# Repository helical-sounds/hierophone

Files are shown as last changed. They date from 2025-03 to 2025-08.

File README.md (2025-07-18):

# Hierophone

The Hierophone is an instrument designed around resonating a sheet of metal by placing it in an audio feedback loop. By changing the filtering of the audio, the phase and level of feedback, and manipulating the sheet directly, different overtones and sounds can be generated.

The name derives from ancient Greek, being the combination of ἱερά (hiera, 'holy') and φωνή (phōnē, 'voice'), together meaning "Holy Voice".

## Contact

Drop me an email at guy@rumblesan.com

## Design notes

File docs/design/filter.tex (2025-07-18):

\documentclass{article}

\usepackage{amsmath}
\usepackage{graphicx}
\usepackage{enumitem}

\title{Hierophone Filter}
\author{Guy John \\ \texttt{guy@rumblesan.com}}

\begin{document}

\maketitle

\section{Introduction}
Analysis of the Hierophone filter, a basic three-pole low-pass filter built from three cascaded OTA based integrator cells.

\newpage

\subsection{Notations}

\begin{description}
\item $R_i$ is the value of the resistor through which the input signal is fed to the OTA
\item $R_s$ is the value of the resistor at the voltage divider input of the OTA
\item $R_f$ is the value of the resistor through which the integrator output is fed back to the OTA input
\item $C$ is the value of the integrators' capacitor
\item $v_{cv}$ is the cutoff frequency control voltage
\item $v_i(s)$ is the input voltage
\item $v_{out}(s)$ is the output voltage
\end{description}

\subsection{OTA Low-Pass Filter}

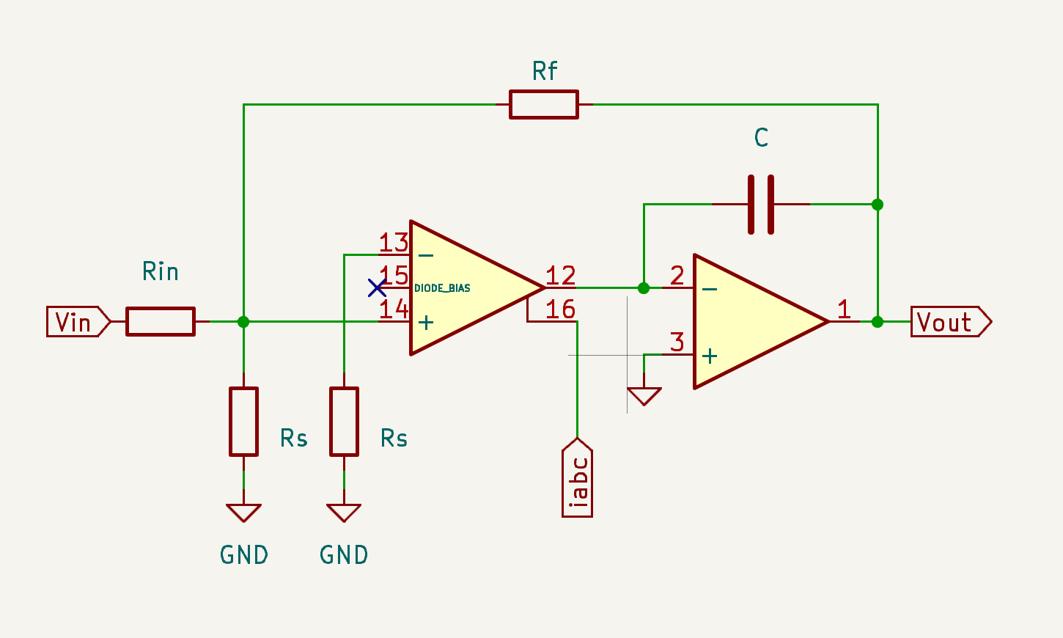
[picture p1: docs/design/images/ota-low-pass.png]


The transfer function of an OTA is:

\begin{equation*}
\begin{split}
  i_o & = g_m(v_+ - v_-) \\
  i_o & = 19.2i_{cv}(v_+ - v_-) \\
\end{split}
\end{equation*}

If $R_f == R_i == R$ then Kirchoff in $v_+$ gives:

\begin{equation*}
\begin{split}
  \frac{1}{R}(v_i(s) - v_+(s)) + \frac{1}{R}(v_{out}(s) - v_+(s)) & = \frac{1}{R_s}v_+(s) \\
  v_+(s) & = \frac{R_s}{R + 2R_s}(v_i(s) + v_{out}(s)) \\
\end{split}
\end{equation*}

Given that $v_-$ is grounded, the current $i_c(s)$ at the output of the OTA is:

\begin{equation*}
\begin{split}
  i_c(s) & = g_m(v_+(s) - v_-(s)) \\
   & = 19.2i_{cv}\frac{R_s}{R + 2R_s}(v_i(s) + v_{out}(s)) \\
\end{split}
\end{equation*}

The voltage out of the OpAmp:

\begin{equation*}
\begin{split}
  v_{out}(s) & = \frac{-i_c(s)}{Cs} \\
  v_{out}(s) & = -19.2i_{cv}\frac{R_s}{Cs(R + 2R_s)}(v_i(s) + v_{out}(s)) \\
\end{split}
\end{equation*}

So the transfer function is:

\begin{equation}
  \alpha(s) = \frac{-1}{1 + \frac{R + 2 R_s}{R_s} Cs \frac{1}{19.2 i_{cv}}}
\end{equation}

The pole is at the frequency f so that:

\begin{equation*}
\begin{split}
  0 & = 1 + \frac{R + 2R_s}{R_s} C2\pi f \frac{1}{19.2 i_{cv}} \\
  f & = - \frac{19.2 i_{cv}}{2\pi\frac{R + 2 R_s}{R_s}C}\\
\end{split}
\end{equation*}

\subsection{Feedback Control}

The gain of the feedback circuit is:

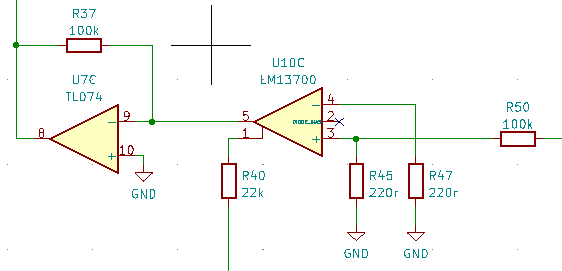
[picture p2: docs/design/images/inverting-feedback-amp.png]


\begin{equation*}
\begin{split}
  v_+ & = v_i\frac{R_s}{R + R_s} \\
  i_o & = 19.2i_{q}(v_+ - v_-) \\
  i_o & = 19.2i_{q}(v_+ - 0) \\
  i_o & = 19.2i_{q}v_i\frac{R_s}{R + R_s} \\
  i_o & = R_f(v_- - v_o) \\
  i_o & = -R_fv_o \\
  -R_fv_o & = 19.2i_{q}v_i\frac{R_s}{R + R_s} \\
  -R_fv_o & = 19.2i_{q}v_i\frac{R_s}{R + R_s} \\
  v_o & = -19.2i_{q}v_i\frac{R_fR_s}{R_i + R_s} \\
  \beta & = -19.2i_{q}\frac{R_fR_s}{R_i + R_s} \\
\end{split}
\end{equation*}

\subsection{Filter}

\begin{equation*}
\begin{split}
  \frac{v_i - v_-}{R_i} + \frac{v_{hp} - v_-}{R_g} + \frac{v_{lp} - v_-}{R_g}  + \frac{v_{bp}\beta - v_-}{R_q} & = i_- = 0 \\
  \frac{v_i}{R_i} + \frac{v_{hp}}{R_g} + \frac{v_{lp}}{R_g}  + \frac{v_{bp}\beta}{R_q} & = 0 \\
\end{split}
\end{equation*}

It is important to note that $v_{bp}(s) = v_{hp}(s)\alpha(s)$, and $v_{lp}(s) = v_{hp}(s)\alpha(s^2)$.

\subsubsection{High-pass}

\begin{equation*}
\begin{split}
  \frac{v_{hp}(s)}{R_g} & = - \frac{v_i(s)}{R_i} - \frac{v_{lp}(s)}{R_g} - \frac{v_{bp}(s)\beta}{R_q} \\
  \frac{v_{hp}(s)}{R_g} & = - \frac{v_i(s)}{R_i} - \frac{v_{hp}(s)\alpha(s^2)}{R_g} - \frac{v_{hp}(s)\alpha(s)\beta}{R_q} \\
  \frac{v_i(s)}{R_i} & = - \frac{v_{hp}(s)}{R_g} - \frac{v_{hp}(s)\alpha(s^2)}{R_g} - \frac{v_{hp}(s)\alpha(s)\beta}{R_q} \\
  H_{hp}(s) & = \frac{v_{hp}(s)}{v_i(s)} \\
  \frac{v_i(s)}{R_i} & = - v_{hp}(s)(\frac{1}{R_g} + \frac{\alpha(s^2)}{R_g} + \frac{\alpha(s)\beta}{R_q}) \\
  \frac{1}{R_i} & = - H_{hp}(s)(\frac{1}{R_g} + \frac{\alpha(s^2)}{R_g} + \frac{\alpha(s)\beta}{R_q}) \\
  \frac{-1}{R_i} & = H_{hp}(s)(\frac{1}{R_g} + \frac{\alpha(s^2)}{R_g} + \frac{\alpha(s)\beta}{R_q}) \\
  H_{hp}(s) & = \frac{-1/R_i}{\frac{1}{R_g} + \frac{\alpha(s^2)}{R_g} + \frac{\alpha(s)\beta}{R_q}} \\
  & = \frac{-R_g/R_i}{1 + \frac{R_g\alpha(s)\beta}{R_q} + \alpha(s^2) } \\
\end{split}
\end{equation*}

\subsubsection{Low-Pass}

\begin{equation*}
\begin{split}
  H_{lp}(s) & = \frac{v_{lp}(s)}{v_i(s)} \\
            & = \frac{v_{hp}(s)}{v_i(s)}\alpha^2(s) \\
            & = \frac{-R_g/R_i}{\frac{1}{\alpha^2(s)} + \frac{R_g\beta}{R_q\alpha(s)} + 1 } \\
            & = \frac{-R_g/R_i}{\frac{1}{\alpha^2(s)} + \beta\frac{R_g}{R_q}\frac{1}{\alpha(s)} + 1 } \\
            & = \frac{-R_g/R_i}{\frac{1}{(-19.2i_{cv}\frac{R_s}{Cs(R + 2R_s)})^2} + (-19.2i_{q}\frac{R_fR_s}{R_i + R_s})\frac{R_g}{R_q}\frac{1}{-19.2i_{cv}\frac{R_s}{Cs(R + 2R_s)}} + 1 } \\
            & = \frac{-R_g/R_i}{\frac{1}{(19.2i_{cv}\frac{R_s}{Cs(R + 2R_s)})^2} + 19.2i_{q}\frac{R_fR_s}{R_i + R_s}\frac{R_g}{R_q}\frac{1}{19.2i_{cv}\frac{R_s}{Cs(R + 2R_s)}} + 1 } \\
            & = \frac{-R_g/R_i}{\frac{1}{\frac{1}{s^2}(19.2i_{cv}\frac{R_s}{C(R + 2R_s)})^2} + 19.2i_{q}\frac{R_fR_s}{R_i + R_s}\frac{R_g}{R_q}\frac{1}{19.2i_{cv}\frac{1}{s}\frac{R_s}{C(R + 2R_s)}} + 1 } \\
            & = \frac{-R_g/R_i}{\frac{s^2}{(19.2i_{cv}\frac{R_s}{C(R + 2R_s)})^2} + 19.2i_{q}\frac{R_fR_s}{R_i + R_s}\frac{R_g}{R_q}\frac{s}{19.2i_{cv}\frac{R_s}{C(R + 2R_s)}} + 1 } \\
\end{split}
\end{equation*}

One simplification worth making is to say that $R_q = R_g$.

By comparing with the standard form of a second order filter transfer function we can work out the following.

\begin{description}
  \item Pass-band gain, $-\frac{R_g}{R_i}$
  \item Cutoff frequency, $19.2i_{cv}\frac{R_s}{C2\pi(R + 2R_s)}$
  \item Quality factor, $\frac{1}{19.2i_{q}\frac{R_fR_s}{R_i + R_s}}$
\end{description}

\subsection{Calculating cutoff frequencies}

Given the calculation for frequency, and picking some standard values we can calculate cutoff for different $i_{cv}$ values.

\begin{description}
  \item $R$ is 100k
  \item $R_s$ is 220r
  \item $C$ is 220pF
\end{description}

\begin{equation}
  f = 19.2i_{cv}\frac{220}{220 * 10^{-12} * 2\pi(100000 + 2(220))}
\end{equation}

\begin{description}
  \item for $i_{cv}$ of 0.5ma $f = 15212Hz$
  \item for $i_{cv}$ of 0.3ma $f = 9127Hz$
  \item for $i_{cv}$ of 0.1ma $f = 3042Hz$
  \item for $i_{cv}$ of 0.05ma $f = 1521Hz$
  \item for $i_{cv}$ of 0.01ma $f = 304Hz$
\end{description}

\subsection{Calculating resonance}

A quality factor of $1/2$ gives no resonance, whilst the resonance (and likelihood of self oscillating) increases as Q goes to infinity.

\begin{description}
  \item $R_f$ is 100k
  \item $R_i$ is 100k
  \item $R_s$ is 220r
  \item $C$ is 220pF
\end{description}

\begin{equation}
  q = \frac{1}{19.2i_{q}\frac{100000 * 220}{100000 + 220}}
\end{equation}

\begin{description}
  \item for $i_{q}$ of 0.5ma $q = 0.47$
  \item for $i_{q}$ of 0.3ma $q = 0.79$
  \item for $i_{q}$ of 0.1ma $q = 2.37$
  \item for $i_{q}$ of 0.05ma $q = 4.75$
  \item for $i_{q}$ of 0.01ma $q = 23.7$
\end{description}

\end{document}

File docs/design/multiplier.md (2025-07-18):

# multiplier

control current circuitry

iabc = Vc/100k * (1k5 + 33k)/1k5

5 = 1.15ma
1.2 = 0.05 * (r + 33k)/r
1.2r = 0.05r + 1.65
1.15r = 1.65

0v   = 0ma
2.5v = 0.575ma
5v   = 1.15ma

OTA current out = 19.2 * iabc * vIn * 220/(100k+220)
vOut = vIn - (OTA current out * 47k)
vOut = vIn - (vIn * iabc * 0.042 * 47k)
vOut/vIn = Gain = 1 - iabc * 0.042 * 47k

Think control circuitry pot directions need flipping

0v input should be gain of 1

2.5v input should be gain of 0
2.5v == 0.575ma
0 = 1 - 0.575 * 0.042 * Rout
0.02415 Rout = 1
Rout should be 41k

5v input should be gain of -1
5v == 1.7ma
-1 = 1 - 1.7 * 0.042 * 28k
0.0714 Rout = 2
Rout should be 28k

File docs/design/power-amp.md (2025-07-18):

# Power Amp Design

The power amp for the Heirophone is just an LM386 powered from the +12v supply. To make sure the chip doesn't overheat and blow up, it's important to work out the voltage input range for a given power output and make sure it operates within those limits.

The [LM386 data sheet][lm386-datasheet] gives all the required information.

When running from a 12v supply, and running into a 4ohm load like the surface transducer, the peak-to-peak output voltage will max out at about 3.8 volts. This means the maximum power output we'll be able to get would be :-

```
vRMS = (vPtoP / 2) * 0.707
vRMS = 1.3433v

power = (vRMS ^ 2) / 4ohms = 0.45W
```

Based on the distortion figures, as well as the devices power dissipation based on power output, the aim is to keep the actual power output to about 0.13W maximum. This means the peak to peak voltage across the speaker should be roughly :-

```
sqrt(0.13W * 4ohms) = 0.721 vRMS

(0.721 vRMS / 0.707) * 2 = 2.04 vPtoP
```

Given the default gain of the LM386 is 20, this means the input voltage should be around 0.1 vPtoP

In theory the output from the opamp just prior to the power amp could be 12 vPtoP meaning ideally there is a gain reduction of 120 to keep within the right limits.

[lm386-datasheet]: https://www.ti.com/lit/ds/symlink/lm386.pdf

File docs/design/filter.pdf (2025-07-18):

# Hierophone Filter

Guy John
guy@rumblesan.com

July 14, 2025

## 1 Introduction

Analysis of the Hierophone filter, a basic three-pole low-pass filter built from three cascaded OTA based integrator cells.

1

### 1.1 Notations

Ri

is the value of the resistor through which the input signal is fed to the OTA

Rs is the value of the resistor at the voltage divider input of the OTA

Rf is the value of the resistor through which the integrator output is fed back to the OTA input

C is the value of the integrators’ capacitor

vcv is the cutoff frequency control voltage

vi(s) is the input voltage

vout(s) is the output voltage

### 1.2 OTA Low-Pass Filter

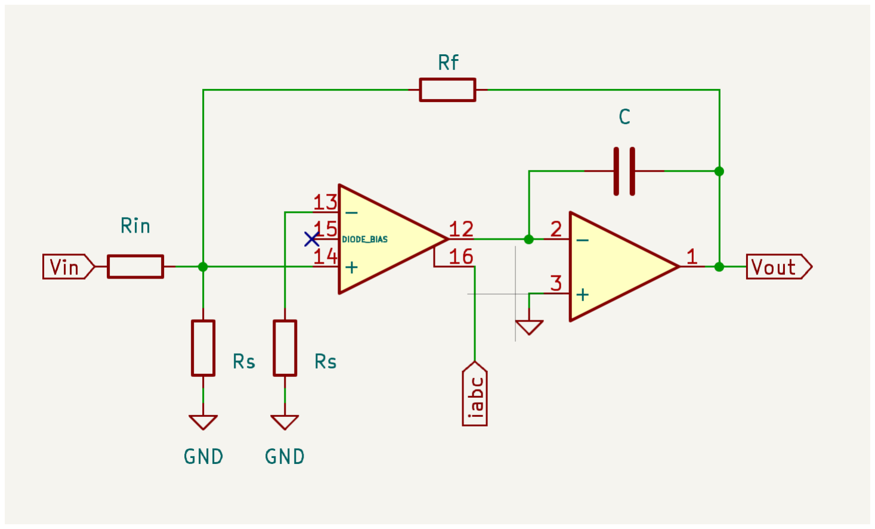
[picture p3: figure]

The transfer function of an OTA is:

io = gm(v+ − v−)
io = 19.2icv(v+ − v−)

If Rf == Ri == R then Kirchoff in v+ gives:

1
R

(vi(s) − v+(s)) + 1
R

(vout(s) − v+(s)) = 1
Rs

v+(s)

v+(s) = Rs R + 2Rs
(vi(s) + vout(s))

2

Given that v− is grounded, the current ic(s) at the output of the OTA is:

ic(s) = gm(v+(s) − v−(s))

= 19.2icv

Rs
R + 2Rs

(vi(s) + vout(s))

The voltage out of the OpAmp:

vout(s) = −ic(s)
Cs

vout(s) = −19.2icv

Rs
Cs(R + 2Rs)

(vi(s) + vout(s))

So the transfer function is:

α(s) = | −1

1 + R+2Rs
Rs

Cs 1
19.2icv

(1)

The pole is at the frequency f so that:

0 = 1 +

R + 2Rs
Rs

C2πf 1 19.2icv

f = −

19.2icv
2π

R+2Rs
Rs

C

### 1.3 Feedback Control

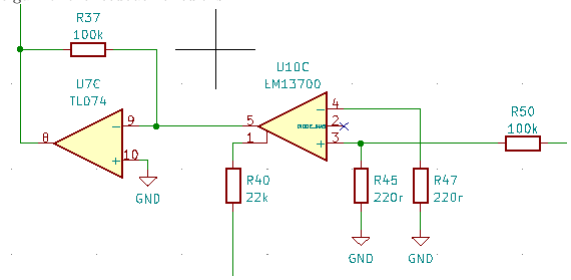
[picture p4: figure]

The gain of the feedback circuit is:

3

v+ = vi

Rs
R + Rs
io = 19.2iq(v+ − v−)
io = 19.2iq(v+ − 0)

io = 19.2iqvi

Rs
R + Rs
io = Rf (v− − vo)
io = −Rf vo

−Rf vo = 19.2iqvi

Rs
R + Rs

−Rf vo = 19.2iqvi

Rs
R + Rs

vo = −19.2iqvi

RfRs
Ri + Rs

β = −19.2iq

RfRs
Ri + Rs

### 1.4 Filter

vi − v−
Ri

+

vhp − v−
Rg

+

vlp − v−
Rg

+

vbpβ − v−
Rq

= i− = 0

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
vbpβ
Rq

= 0

It is important to note that vbp(s) = vhp(s)α(s), and vlp(s) = vhp(s)α(s

2
).

4

### 1.4.1 High-pass

vhp(s)
Rg

= −

vi(s)
Ri

−

vlp(s)
Rg

−

vbp(s)β
Rq
vhp(s)
Rg

= −

vi(s)
Ri

−

vhp(s)α(s

2
)
Rg

−

vhp(s)α(s)β
Rq
vi(s)
Ri

= −

vhp(s)
Rg

−

vhp(s)α(s

2
)
Rg

−

vhp(s)α(s)β
Rq
Hhp(s) = vhp(s)
vi(s)
vi(s)
Ri

= −vhp(s)( 1
Rg

+

α(s

2
)
Rg

+

α(s)β
Rq

)

1
Ri

= −Hhp(s)( 1
Rg

+

α(s

2
)
Rg

+

α(s)β
Rq

)

−1
Ri

= Hhp(s)( 1
Rg

+

α(s

2
)
Rg

+

α(s)β
Rq

)

Hhp(s) = | −1/Ri

1
Rg

+

| α(s 2) Rg +
α(s)β
Rq
= | −Rg/Ri 1 + Rgα(s)β Rq + α(s

2)

5

### 1.4.2 Low-Pass

Hlp(s) = vlp(s)
vi(s)

=

vhp(s)
vi(s)

α

2
(s)

=

−Rg/Ri

1
α²(s) +

Rgβ
Rqα(s) + 1

=

−Rg/Ri

1
α²(s) + β

Rg
Rq

1
α(s) + 1

=

−Rg/Ri

1
(−19.2icv

Rs
Cs(R+2Rs)

)

2 + (−19.2iq

Rf Rs
Ri+Rs

)

Rg
Rq

1
−19.2icv

Rs
Cs(R+2Rs)

+ 1

=

−Rg/Ri

1
(19.2icv

Rs
Cs(R+2Rs)

)

2 + 19.2iq

Rf Rs
Ri+Rs

Rg
Rq

1
19.2icv

Rs
Cs(R+2Rs)

+ 1

=

−Rg/Ri

1
1
s2

(19.2icv

Rs
C(R+2Rs)

)

2 + 19.2iq

Rf Rs
Ri+Rs

Rg
Rq

1
19.2icv

1
s

Rs
C(R+2Rs)

+ 1

=

−Rg/Ri

s

2
(19.2icv

Rs
C(R+2Rs)

)

2 + 19.2iq

Rf Rs
Ri+Rs

Rg
Rq

s
19.2icv

Rs
C(R+2Rs)

+ 1

One simplification worth making is to say that Rq = Rg.
By comparing with the standard form of a second order filter transfer function we can work out the following.

Pass-band gain, −

Rg
Ri

Cutoff frequency, 19.2icv

Rs
C2π(R+2Rs)
Quality factor, 1
19.2iq
| Rf Rs Ri+Rs

### 1.5 Calculating cutoff frequencies

Given the calculation for frequency, and picking some standard values we can calculate cutoff for different icv values.

R is 100k

Rs is 220r

C is 220pF

f = 19.2icv

220
220 ∗ 10⁻¹² ∗ 2π(100000 + 2(220)) | (2)

6

for icv of 0.5ma f = 15212Hz

for icv of 0.3ma f = 9127Hz

for icv of 0.1ma f = 3042Hz

for icv of 0.05ma f = 1521Hz

for icv of 0.01ma f = 304Hz

### 1.6 Calculating resonance

A quality factor of 1/2 gives no resonance, whilst the resonance (and likelihood of self oscillating) increases as Q goes to infinity.

Rf is 100k

Ri

is 100k

Rs is 220r

C is 220pF

q =

1
19.2iq

100000∗220
100000+220

(3)

for iq of 0.5ma q = 0.47

for iq of 0.3ma q = 0.79

for iq of 0.1ma q = 2.37

for iq of 0.05ma q = 4.75

for iq of 0.01ma q = 23.7

7

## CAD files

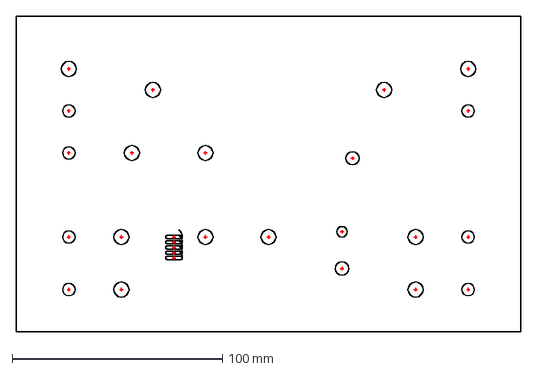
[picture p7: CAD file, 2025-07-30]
panels/panel-holes.dxf
240.0 x 150.0 mm

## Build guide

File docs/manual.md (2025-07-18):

# Hierophone

The Hierophone is an instrument designed around resonating a sheet of metal by placing it in an audio feedback loop. By changing the filtering of the audio, the phase and level of feedback, and manipulating the sheet directly, different overtones and sounds can be generated.

The name derives from ancient Greek, being the combination of ἱερά (hiera, 'holy') and φωνή (phōnē, 'voice'), together meaning "Holy Voice".

## Background

At the beginning of 2025 I visited the home/workshop of [Sam Underwood](https://www.mrunderwood.co.uk/) where he showed a wild range of interesting instruments and oddities he'd designed and made. One of these involved using part of his "Acoustic Modular" to excite a small steel plate with a surface transducer, pick the sound up using a piezo contact microphone, and then feed the output back to the input to make the plate resonate, using a low pass filter and some magnets to influence the sound.

It was great!
So I decided to build my own version.

## Warnings

It is very easy to make a lot of loud, dissonant, screeching noise with the Hierophone. Whilst this is obviously part of the appeal of the instrument, it's worth exercising a bit of caution when first getting used to playing it.

As well as potentially painful sounds, it's also worth pointing out that a thin sheet of steel can have potentially sharp edges and cause damage to tabletops, floors, furniture and hands if you're not careful with it.

## Power

The Hierophone is designed to be run from a 9 volt, centre negative power supply. It should also work fine from 12 volts, but prolonged usage will make the power amp a bit warmer.

## Operation

The signal flow of the Hierophone is relatively simple, with the complexity really coming from the interaction of everything. Whilst it has audio inputs and outputs, it can be played alone with the sounds generated by the plate itself.

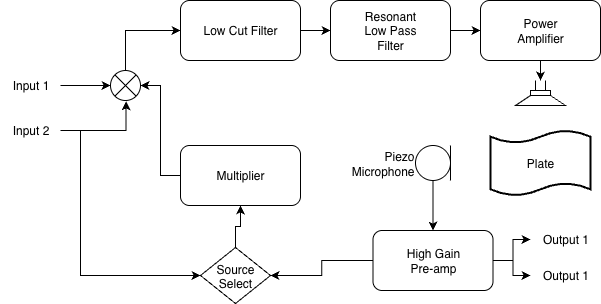
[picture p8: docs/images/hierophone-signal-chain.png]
Hierophone Signal Chain


#### Inputs

There are two inputs, both with individual volume controls, which can accept both line-level and modular synth level signals. These are mixed together along with the audio being fed back from the output.

#### Low-cut Filter

It can sometimes be useful to cut some of the low frequencies being fed into the plate to try and make it resonate with higher harmonics. This is a basic 6db/octave, non-resonant, high-pass filter with a variable frequency cut-off from about 350Hz down to 0Hz.

#### Resonant Low-pass Filter

Audio feedback can result in a lot of high frequencies, especially with the steel plate resonance. This filter helps to tame that, as well as allowing some influence over how the plate resonates and what overtones will sound out.

It is a three-pole, 18db/octave, low-pass filter with control over the cut-off frequency and resonance. The cut-off is also CV controllable by another source, with an attenuverter on the input.

#### Power Amplifier

The power amplifier is responsible for driving the surface transducer that excites the plate. The "Plate Drive" controls how much the surface transducer will be driven by the amplifier.

#### Surface Transducer

The transducers

#### High-Gain Piezo Amplifier

An amplifier designed specifically to handle the high output impedance of a piezo contact microphone. The "Pickup Gain" controls how much the input from the piezo is amplified.

#### Feedback Multiplier

When interacting with feedback in complex systems, the phase of the signal can be as important as the magnitude in changing how the system behaves. The multiplier allows smoothly changing both of these things with a single control. Fully clockwise will feed the full signal back to the input, while fully anti-clockwise will still feed the full signal, but inverted to be 180 degrees out of phase.

Positioning the control at 12 o'clock will result in no signal being fed back to the input.

This parameter is also fully CV controllable with an attenuverter on the input. It's worth noting that if you have an external oscillator then the multiplier can function as a ring-modulator, giving access to all sorts of metallic sound generation.

Finally, there is a switch to select whether the audio fed back to the input comes from the piezo amplifier, or instead from the second input before its volume control. This makes it possible to add other equipment into the feedback loop by taking the audio from one of the outputs, passing it through external processing, and then directly back into the multiplier.

#### Outputs

There are two outputs, each with their own separate volume control. These will not function as headphone outputs.

## Playing

Ultimately how you play the Hierophone is up to you, and like anything weird it rewards experimentation. That said, here are a few pointers to help give you some starting directions.

* Cranking the drive, pick-up gain and/or feedback can result in a very noisy experience. This may be what you're going for, but there's a lot of interesting sounds possible when the circuit is just on the edge of fully resonating.
* Manipulating the plate carefully can change the overtones being generated in quite a subtle way. Try bending it while it resonates to see how the sounds changes.
* Touching different points on the plate can also make certain harmonics appear and disappear as the pressure of a finger creates dead spots. If you want to explore this more then it can be useful to prop the plate up on something so it's not laying flat on a table and has more space to vibrate.
* By giving the filter some resonance it can be used to force it to play different overtones. This frequency could then be sequenced from another piece of gear to give movement while the other controls on the instrument are explored.

## Thanks

Sam Underwood for the initial idea.
James Wheale for always supporting the weird stuff I do and getting me to make more of it.

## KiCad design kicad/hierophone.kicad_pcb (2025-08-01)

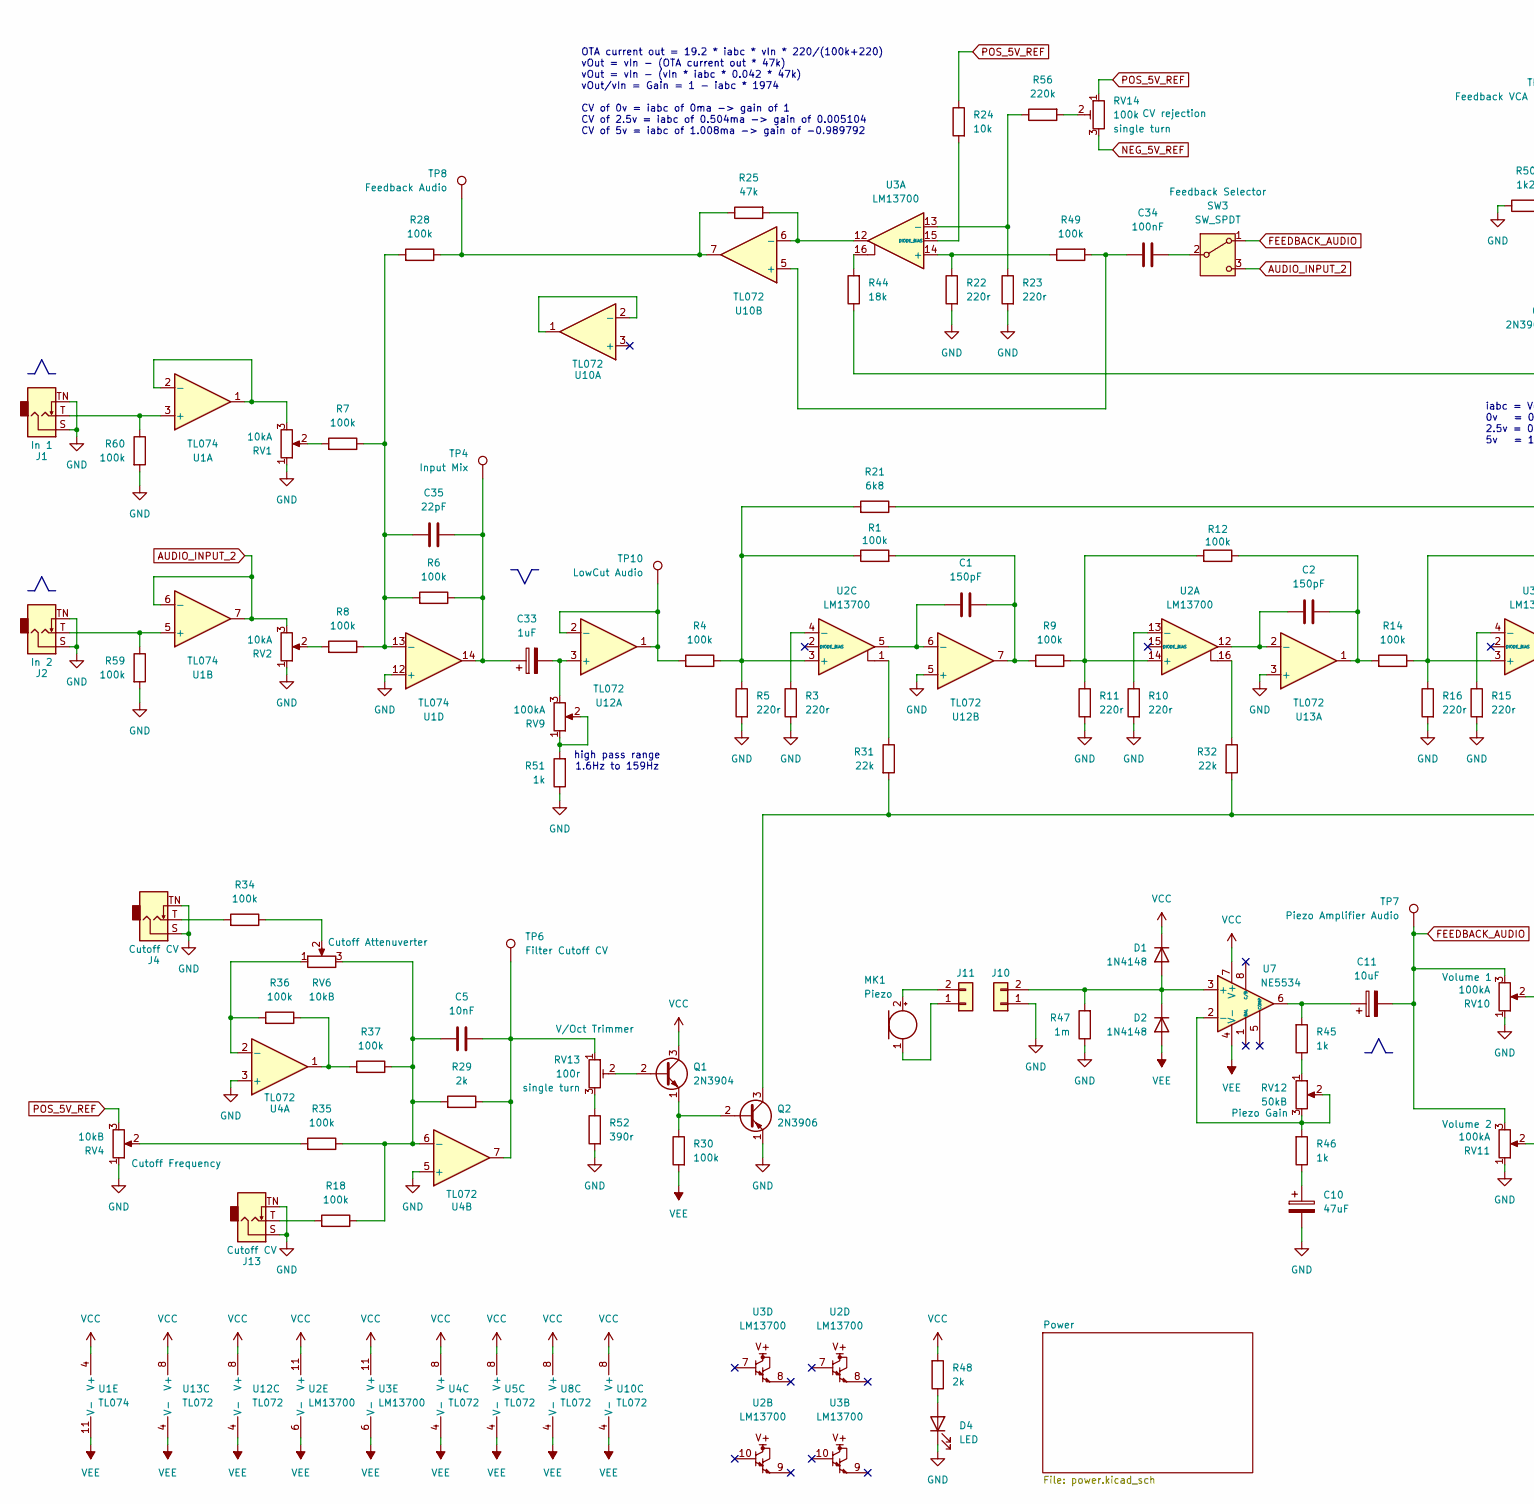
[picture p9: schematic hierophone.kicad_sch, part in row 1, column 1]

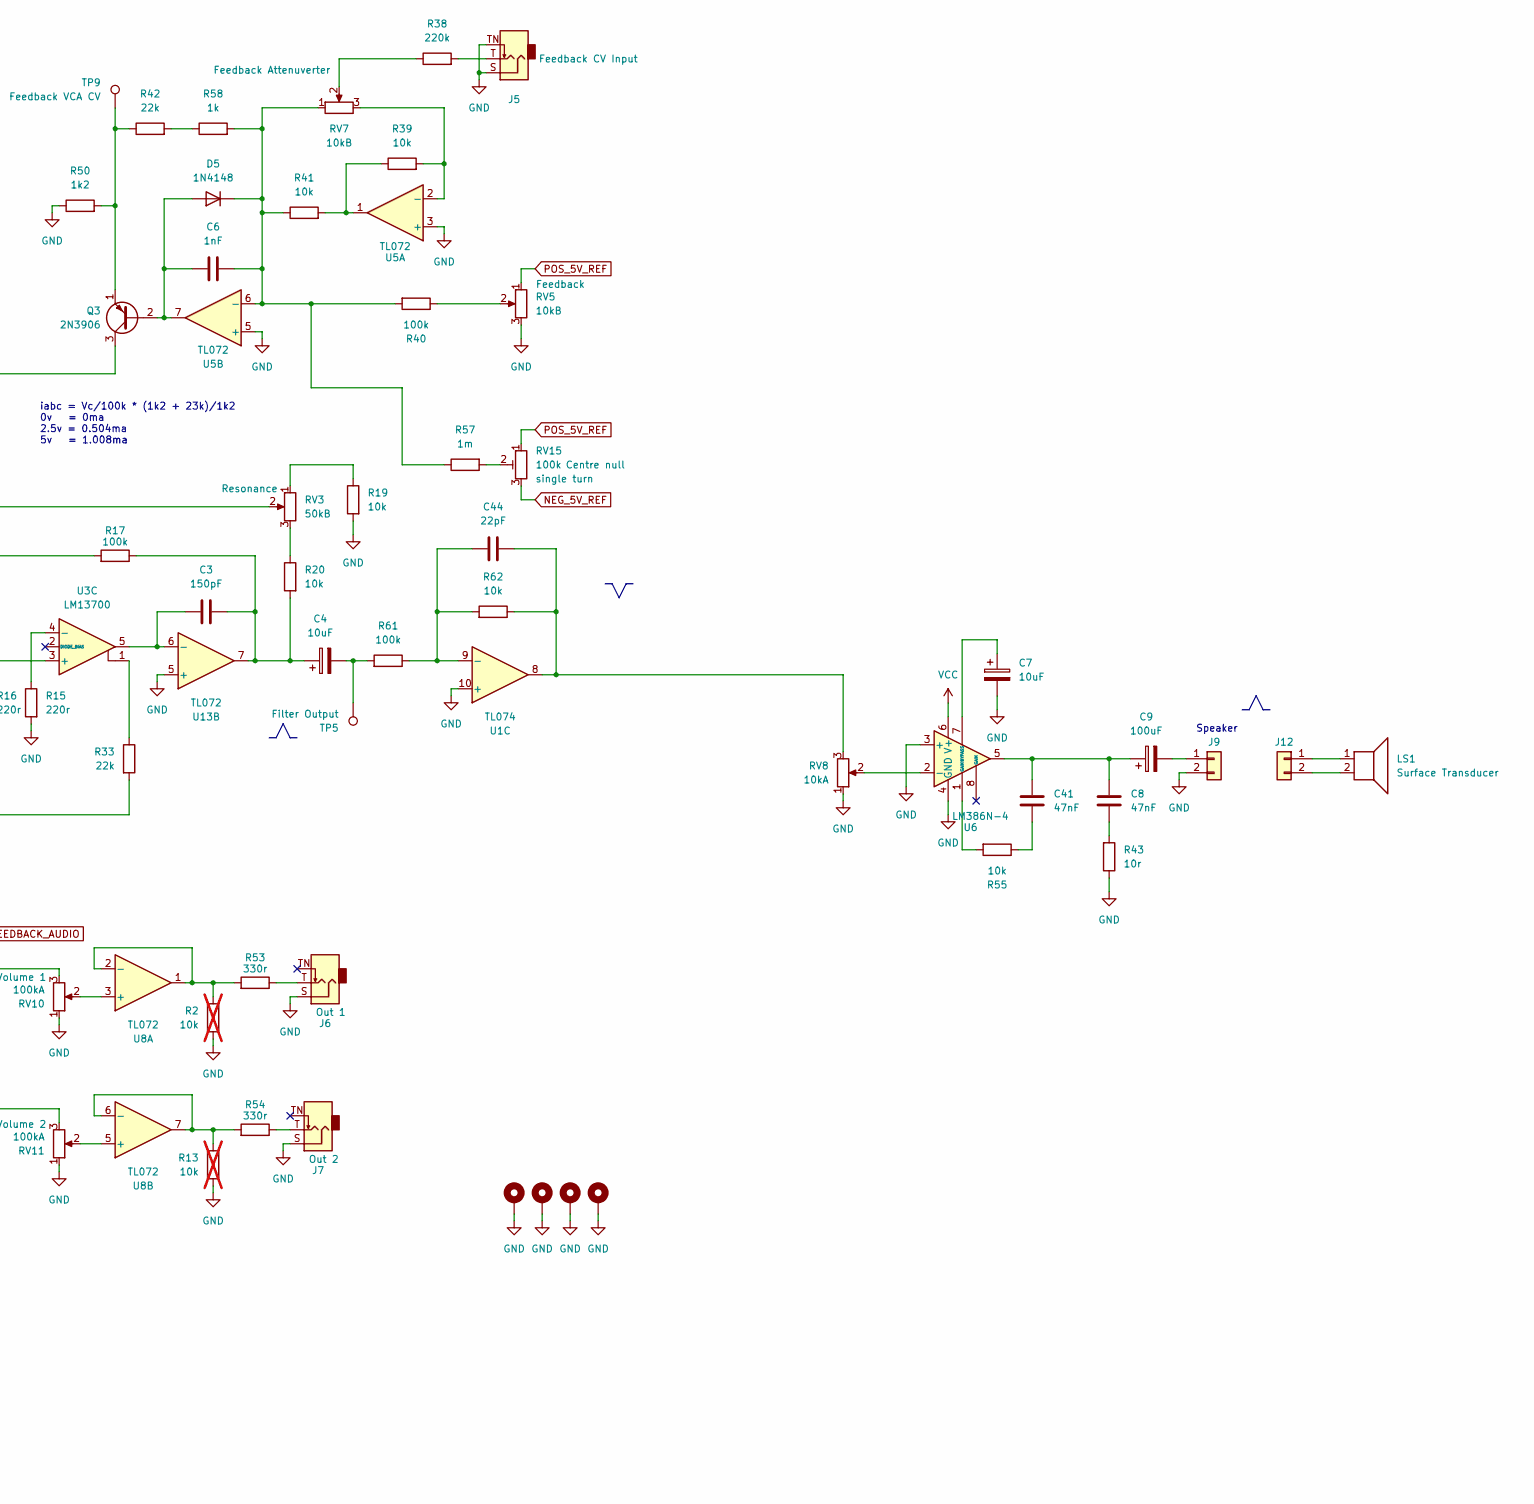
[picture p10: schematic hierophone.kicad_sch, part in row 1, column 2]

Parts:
C1, C2, C3: 150pF; C_Rect_L7.0mm_W4.5mm_P5.00mm; Tolerance 5%
C4, C7, C11: 10uF; CP_Radial_D5.0mm_P2.00mm; Tolerance 20%; Voltage 50v
C5: 10nF; C_Rect_L7.0mm_W2.5mm_P5.00mm; Tolerance 5%
C6: 1nF; C_Rect_L7.0mm_W2.5mm_P5.00mm; Tolerance 5%
C8, C41: 47nF; C_Rect_L7.0mm_W2.5mm_P5.00mm; Tolerance 5%
C9: 100uF; CP_Radial_D5.0mm_P2.00mm; Tolerance 20%; Voltage 50v
C10: 47uF; CP_Radial_D5.0mm_P2.00mm; Tolerance 20%; Voltage 50v
C33: 1uF; CP_Radial_D5.0mm_P2.00mm; Tolerance 20%; Voltage 50v
C34: 100nF; C_Rect_L7.0mm_W2.5mm_P5.00mm; Tolerance 5%
C35, C44: 22pF; C_Rect_L7.0mm_W2.5mm_P5.00mm; Tolerance 5%
D1, D2, D5: 1N4148; D_DO-35_SOD27_P7.62mm_Horizontal
D4: LED; LED_D5.0mm
H1, H2, H3, H4: MountingHole_Pad; MountingHole_3.2mm_M3_Pad
J1, J2, J4, J5, J6, J7, J13: AudioJack2_SwitchT; Jack_3.5mm_QingPu_WQP-PJ398SM_Vertical
J9, J10, J11, J12: Conn_01x02; Molex_KK-254_22-05-7028_1x02_P2.54mm_Horizontal
LS1: Surface Transducer
MK1: Piezo; PinHeader_1x02_P2.54mm_Vertical
Q1: 2N3904; TO-92_Inline_Wide
Q2, Q3: 2N3906; TO-92_Inline_Wide
R1, R4, R6, R7, R8, R9, R12, R14, R17, R18, R28, R30, R34, R35, R36, R37, R40, R49, R59, R60, R61: 100k; R_Axial_DIN0207_L6.3mm_D2.5mm_P10.16mm_Horizontal; Tolerance 1%
R2, R13: 10k; R_Axial_DIN0207_L6.3mm_D2.5mm_P10.16mm_Horizontal; Tolerance 1%; not fitted
R3, R5, R10, R11, R15, R16, R22, R23: 220r; R_Axial_DIN0207_L6.3mm_D2.5mm_P10.16mm_Horizontal; Tolerance 1%
R19, R20, R24, R39, R41, R55, R62: 10k; R_Axial_DIN0207_L6.3mm_D2.5mm_P10.16mm_Horizontal; Tolerance 1%
R21: 6k8; R_Axial_DIN0207_L6.3mm_D2.5mm_P10.16mm_Horizontal; Tolerance 1%
R25: 47k; R_Axial_DIN0207_L6.3mm_D2.5mm_P10.16mm_Horizontal; Tolerance 1%
R29, R48: 2k; R_Axial_DIN0207_L6.3mm_D2.5mm_P10.16mm_Horizontal; Tolerance 1%
R31, R32, R33, R42: 22k; R_Axial_DIN0207_L6.3mm_D2.5mm_P10.16mm_Horizontal; Tolerance 1%
R38, R56: 220k; R_Axial_DIN0207_L6.3mm_D2.5mm_P10.16mm_Horizontal; Tolerance 1%
R43: 10r; R_Axial_DIN0207_L6.3mm_D2.5mm_P10.16mm_Horizontal; Tolerance 1%
R44: 18k; R_Axial_DIN0207_L6.3mm_D2.5mm_P10.16mm_Horizontal; Tolerance 1%
R45, R46, R51, R58: 1k; R_Axial_DIN0207_L6.3mm_D2.5mm_P10.16mm_Horizontal; Tolerance 1%
R47, R57: 1m; R_Axial_DIN0207_L6.3mm_D2.5mm_P10.16mm_Horizontal; Tolerance 1%
R50: 1k2; R_Axial_DIN0207_L6.3mm_D2.5mm_P10.16mm_Horizontal; Tolerance 1%
R52: 390r; R_Axial_DIN0207_L6.3mm_D2.5mm_P10.16mm_Horizontal; Tolerance 1%
R53, R54: 330r; R_Axial_DIN0207_L6.3mm_D2.5mm_P10.16mm_Horizontal; Tolerance 1%
RV1, RV2, RV8: 10kA; Potentiometer_Alpha_RD901F-40-00D_Single_Vertical
RV3, RV12: 50kB; Potentiometer_Alpha_RD901F-40-00D_Single_Vertical
RV4, RV5, RV6, RV7: 10kB; Potentiometer_Alpha_RD901F-40-00D_Single_Vertical
RV9, RV10, RV11: 100kA; Potentiometer_Alpha_RD901F-40-00D_Single_Vertical
RV13: 100r; Potentiometer_THT_Bourns_3306P_Vertical
RV14, RV15: 100k; Potentiometer_THT_Bourns_3306P_Vertical
SW3: SW_SPDT; Toggle_Switch_100SP-M2
TP4: Input Mix; TestPoint_Loop_D2.50mm_Drill1.0mm_LowProfile
TP5: Filter Output; TestPoint_Loop_D2.50mm_Drill1.0mm_LowProfile
TP6: Filter Cutoff CV; TestPoint_Loop_D2.50mm_Drill1.0mm_LowProfile
TP7: Piezo Amplifier Audio; TestPoint_Loop_D2.50mm_Drill1.0mm_LowProfile
TP8: Feedback Audio; TestPoint_Loop_D2.50mm_Drill1.0mm_LowProfile
TP9: Feedback VCA CV; TestPoint_Loop_D2.50mm_Drill1.0mm_LowProfile
TP10: LowCut Audio; TestPoint_Loop_D2.50mm_Drill1.0mm_LowProfile
U1: TL074; DIP-14_W7.62mm_Socket
U2, U3: LM13700; DIP-16_W7.62mm_Socket
U4, U5, U8, U10, U12, U13: TL072; DIP-8_W7.62mm_Socket
U6: LM386N-4; DIP-8_W7.62mm_Socket
U7: NE5534; DIP-8_W7.62mm_Socket

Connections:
AUDIO_INPUT_2: RV2.3, SW3.3 (C), U1.6 (-), U1.7
FEEDBACK_AUDIO: C11.2, RV10.3, RV11.3, SW3.1 (A), TP7.1
GND: C7.2, C10.2, D4.1 (K), H1.1, H2.1, H3.1, H4.1, J1.S, J1.TN, J2.S, J2.TN, J4.S, J4.TN, J5.S, J5.TN, J6.S, J7.S, J9.2, J10.1, J13.S, J13.TN, Q2.1 (E), R2.2, R3.1, R5.1, R10.1, R11.1, R13.2, R15.1, R16.1, R19.1, R22.1, R23.1, R43.2, R47.2, R50.2, R51.2, R52.1, R59.1, R60.1, RV1.1, RV2.1, RV4.1, RV5.3, RV8.1, RV10.1, RV11.1, U1.10 (+), U1.12 (+), U4.3 (+), U4.5 (+), U5.3 (+), U5.5 (+), U6.3 (+), U6.4 (GND), U12.5 (+), U13.3 (+), U13.5 (+); also elsewhere on the board
NEG_5V_REF: RV14.3, RV15.3; also elsewhere on the board
unnamed: C1.1, R1.1, R9.1, U12.7
unnamed: C2.1, R12.2, R14.1, U13.1
unnamed: C3.1, C4.1, R17.2, R20.1, U13.7
unnamed: C4.2, R61.1, TP5.1
unnamed: C5.2, R29.2, RV13.1, TP6.1, U4.7
unnamed: C8.2, R43.1
unnamed: C10.1, R46.2
unnamed: C11.1, R45.1, U7.6
unnamed: C33.1, C35.1, R6.2, TP4.1, U1.14
unnamed: C8.1, C9.1, C41.1, U6.5
unnamed: C41.2, R55.2
unnamed: C44.1, R62.2, RV8.3, U1.8
unnamed: D1.2 (A), D2.1 (K), J10.2, R47.1, U7.3 (+)
unnamed: D4.2 (A), R48.2
unnamed: C6.2, D5.2 (A), Q3.2 (B), U5.7
unnamed: C6.1, D5.1 (K), R40.1, R41.2, R57.2, R58.1, RV7.1, U5.6 (-)
unnamed: J4.T, R34.1
unnamed: J5.T, R38.1
unnamed: J6.T, R53.2
unnamed: J7.T, R54.2
unnamed: C9.2, J9.1
unnamed: J11.1, MK1.1 (-)
unnamed: J11.2, MK1.2 (+)
unnamed: J12.1, LS1.1
unnamed: J12.2, LS1.2
unnamed: J13.T, R18.1
unnamed: Q1.2 (B), RV13.2
unnamed: Q1.1 (E), Q2.2 (B), R30.2
unnamed: Q2.3 (C), R31.1, R32.1, R33.1
unnamed: Q3.3 (C), R44.2
unnamed: Q3.1 (E), R42.2, R50.1, TP9.1
unnamed: R7.1, RV1.2
unnamed: R8.1, RV2.2
unnamed: R19.2, RV3.1
unnamed: R20.2, RV3.3
unnamed: R21.2, RV3.2
unnamed: R25.2, R28.2, TP8.1, U10.7
unnamed: R31.2, U2.1
unnamed: R32.2, U2.16
unnamed: R33.2, U3.1
unnamed: R34.2, RV6.2
unnamed: R35.1, RV4.2
unnamed: R36.2, R37.1, U4.1
unnamed: R38.2, RV7.2
unnamed: R39.2, R41.1, U5.1
unnamed: R40.2, RV5.2
unnamed: R42.1, R58.2
unnamed: R44.1, U3.16
unnamed: R45.2, RV12.1
unnamed: R51.1, RV9.1, RV9.2
unnamed: R52.2, RV13.3
unnamed: R55.1, U6.1 (GAIN)
unnamed: R56.1, RV14.2
unnamed: R57.1, RV15.2
unnamed: C34.2, SW3.2 (B)
unnamed: J1.T, R60.2, U1.3 (+)
unnamed: RV1.3, U1.1, U1.2 (-)
unnamed: J2.T, R59.2, U1.5 (+)
unnamed: C44.2, R61.2, R62.1, U1.9 (-)
unnamed: C35.2, R6.1, R7.2, R8.2, R28.1, U1.13 (-)
unnamed: R9.2, R11.2, R12.1, U2.14 (+)
unnamed: R10.2, U2.13 (-)
unnamed: R1.2, R4.2, R5.2, R21.1, U2.3 (+)
unnamed: R3.2, U2.4 (-)
unnamed: R22.2, R49.2, U3.14 (+)
unnamed: R23.2, R56.2, U3.13 (-)
unnamed: R24.1, U3.15 (DIODE_BIAS)
unnamed: R14.2, R16.2, R17.1, U3.3 (+)
unnamed: R15.2, U3.4 (-)
unnamed: R36.1, RV6.1, U4.2 (-)
unnamed: C5.1, R18.2, R29.1, R35.2, R37.2, RV6.3, U4.6 (-)
unnamed: R39.1, RV7.3, U5.2 (-)
unnamed: RV8.2, U6.2 (-)
unnamed: C7.1, U6.7 (BYPASS)
unnamed: R46.1, RV12.2, RV12.3, U7.2 (-)
unnamed: RV10.2, U8.3 (+)
unnamed: R2.1, R53.1, U8.1, U8.2 (-)
unnamed: RV11.2, U8.5 (+)
unnamed: R13.1, R54.1, U8.6 (-), U8.7
unnamed: U10.1, U10.2 (-)
unnamed: C34.1, R49.1, U10.5 (+)
unnamed: R25.1, U3.12, U10.6 (-)
unnamed: C33.2, RV9.3, U12.3 (+)
unnamed: R4.1, TP10.1, U12.1, U12.2 (-)
unnamed: C1.2, U2.5, U12.6 (-)
unnamed: C2.2, U2.12, U13.2 (-)
unnamed: C3.2, U3.5, U13.6 (-)
POS_5V_REF: R24.2, RV4.3, RV5.1, RV14.1, RV15.1; also elsewhere on the board
VCC: D1.1 (K), Q1.3 (C), R48.1, U1.4 (V+), U2.11 (V+), U3.11 (V+), U4.8 (V+), U5.8 (V+), U6.6 (V+), U7.7 (V+), U8.8 (V+), U10.8 (V+), U12.8 (V+), U13.8 (V+); also elsewhere on the board
VEE: D2.2 (A), R30.1, U1.11 (V-), U2.6 (V-), U3.6 (V-), U4.4 (V-), U5.4 (V-), U7.4 (V-), U8.4 (V-), U10.4 (V-), U12.4 (V-), U13.4 (V-); also elsewhere on the board

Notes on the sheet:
high pass range 1.6Hz to 159Hz
Speaker
OTA current out = 19.2 * iabc * vIn * 220/(100k+220) vOut = vIn - (OTA current out * 47k) vOut = vIn - (vIn * iabc * 0.042 * 47k) vOut/vIn = Gain = 1 - iabc * 1974 CV of 0v = iabc of 0ma -> gain of 1 CV of 2.5v = iabc of 0.504ma -> gain of 0.005104 CV of 5v = iabc of 1.008ma -> gain of -0.989792
iabc = Vc/100k * (1k2 + 23k)/1k2 0v = 0ma 2.5v = 0.504ma 5v = 1.008ma

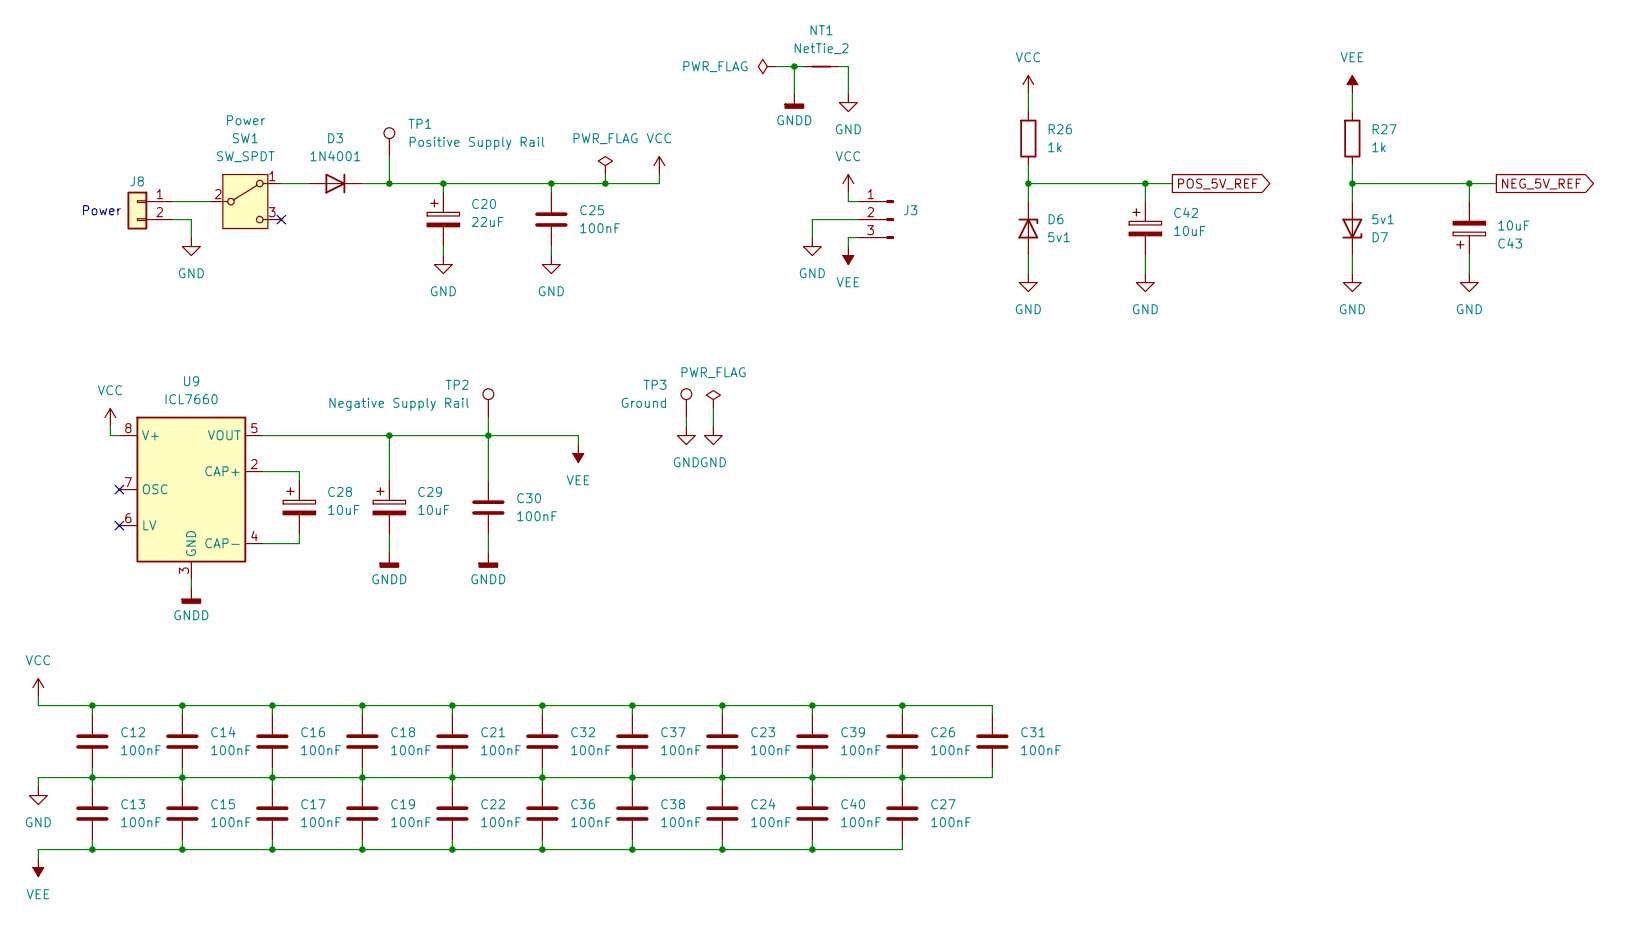
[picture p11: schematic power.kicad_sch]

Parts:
C12, C13, C14, C15, C16, C17, C18, C19, C21, C22, C23, C24, C25, C26, C27, C30, C31, C32, C36, C37, C38, C39, C40: 100nF; C_Rect_L7.0mm_W2.5mm_P5.00mm; Tolerance 5%
C20: 22uF; CP_Radial_D5.0mm_P2.00mm; Tolerance 20%; Voltage 50v
C28, C29, C42, C43: 10uF; CP_Radial_D5.0mm_P2.00mm; Tolerance 20%; Voltage 50v
D3: 1N4001; D_DO-41_SOD81_P10.16mm_Horizontal
D6, D7: 5v1; D_DO-41_SOD81_P10.16mm_Horizontal
J3: Conn_01x03_Pin; Molex_KK-254_22-05-7038_1x03_P2.54mm_Horizontal
J8: Conn_01x02; Molex_KK-254_22-05-7028_1x02_P2.54mm_Horizontal
NT1: NetTie_2; NetTie-2_SMD_Pad2.0mm
R26, R27: 1k; R_Axial_DIN0207_L6.3mm_D2.5mm_P10.16mm_Horizontal; Tolerance 1%
SW1: SW_SPDT; Toggle_Switch_100SP-M2
TP1: Positive Supply Rail; TestPoint_Loop_D2.50mm_Drill1.0mm_LowProfile
TP2: Negative Supply Rail; TestPoint_Loop_D2.50mm_Drill1.0mm_LowProfile
TP3: Ground; TestPoint_Loop_D2.50mm_Drill1.0mm_LowProfile
U9: ICL7660; DIP-8_W7.62mm_Socket

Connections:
GND: C12.2, C13.1, C14.2, C15.1, C16.2, C17.1, C18.2, C19.1, C20.2, C21.2, C22.1, C23.2, C24.1, C25.2, C26.2, C27.1, C31.2, C32.2, C36.1, C37.2, C38.1, C39.2, C40.1, C42.2, C43.1, D6.2 (A), D7.1 (K), J3.2, J8.2, NT1.2, TP3.1; also elsewhere on the board
GNDD: C29.2, C30.2, NT1.1, U9.3 (GND)
NEG_5V_REF: C43.2, D7.2 (A), R27.2; also elsewhere on the board
unnamed: D3.2 (A), SW1.1 (A)
unnamed: J8.1, SW1.2 (B)
unnamed: C28.1, U9.2 (CAP+)
unnamed: C28.2, U9.4 (CAP-)
POS_5V_REF: C42.1, D6.1 (K), R26.2; also elsewhere on the board
VCC: C12.1, C14.1, C16.1, C18.1, C20.1, C21.1, C23.1, C25.1, C26.1, C31.1, C32.1, C37.1, C39.1, D3.1 (K), J3.1, R26.1, TP1.1, U9.8 (V+); also elsewhere on the board
VEE: C13.2, C15.2, C17.2, C19.2, C22.2, C24.2, C27.2, C29.1, C30.1, C36.2, C38.2, C40.2, J3.3, R27.1, TP2.1, U9.5 (VOUT); also elsewhere on the board

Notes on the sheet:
Power

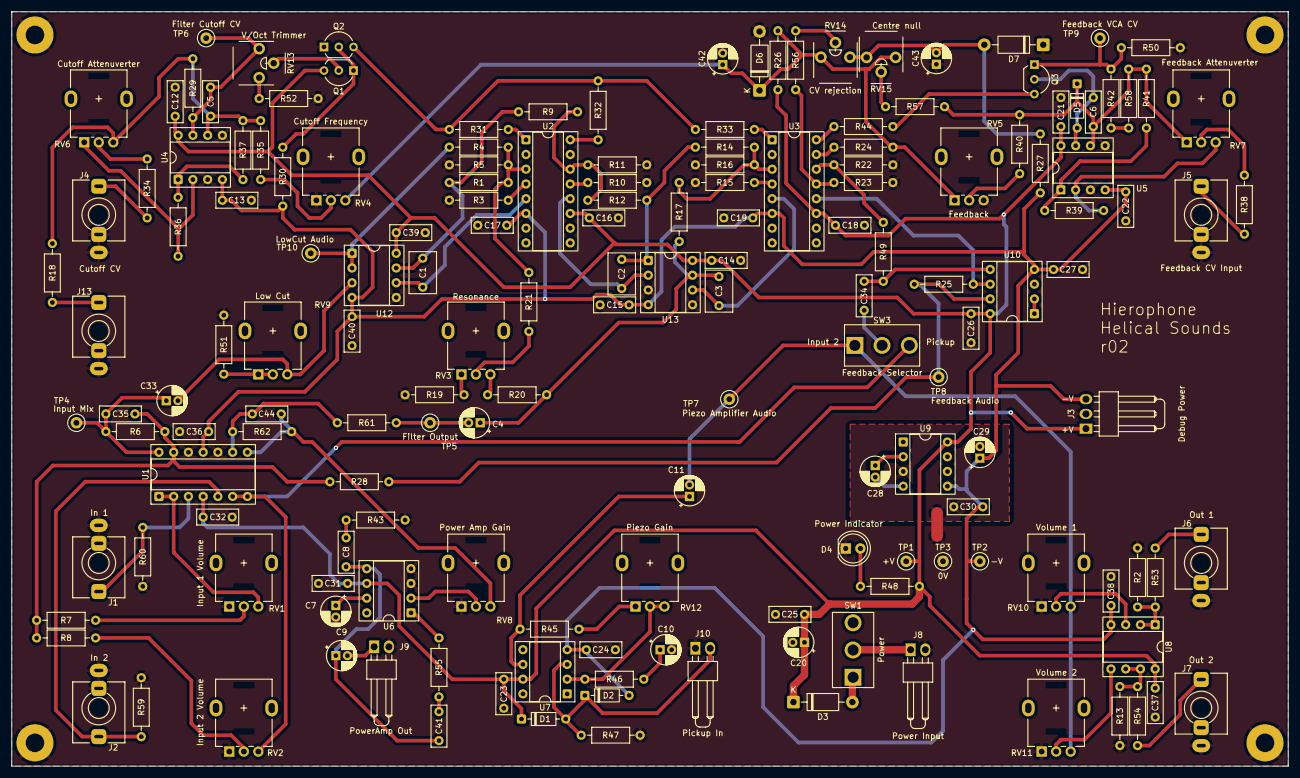
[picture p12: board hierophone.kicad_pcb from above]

Board: 2 copper layers, 220.0 x 130.0 mm, 171 parts (0 on the bottom side), 95 nets.

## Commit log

2025-01-19 Adding rev01 gerbers
    [steel-feedback-B_Cu.gbl, steel-feedback-B_Mask.gbs, steel-feedback-B_Silkscreen.gbo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]
2025-02-07 Tweaking values now that build is in progress
    [power.kicad_sch, steel-feedback.kicad_pcb, steel-feedback.kicad_sch]
2025-03-07 Fixing issues in schematic
    [steel-feedback.kicad_pcb, steel-feedback.kicad_sch]
2025-03-07 Fixing issues with power circuitry
    [power.kicad_sch, steel-feedback.kicad_pcb]
2025-03-30 Adding piezo and surface transducer to schematic
    [steel-feedback.kicad_sch]
2025-03-30 Updating panel with new name and layout tweak
    [panel-holes.dxf]
2025-03-30 Removing old bom.ini file
2025-03-30 Updating kicad project with new name
    [heirophone.kicad_pcb, heirophone.kicad_sch, power.kicad_sch]
2025-03-30 Redesign feedback VCA to be a multiplier
    [heirophone.kicad_pcb, heirophone.kicad_sch]
2025-03-30 Fixing name...
    [hierophone.kicad_pcb, hierophone.kicad_sch, power.kicad_sch]
2025-03-30 Adding version info text to PCB
    [hierophone.kicad_pcb]
2025-07-14 Updating for KiCAD version 9
    [hierophone.kicad_pcb, hierophone.kicad_sch, power.kicad_sch]
2025-07-16 Tweaking PCB
    [hierophone.kicad_pcb, hierophone.kicad_sch, power.kicad_sch]
2025-07-18 Fixing issues with the inputs
    [hierophone.kicad_pcb, hierophone.kicad_sch]
2025-07-18 Adding volt per octave input
    [hierophone.kicad_pcb, hierophone.kicad_sch, panel-holes.dxf]
2025-07-18 Adding basic signal chain diagram
2025-07-18 More pcb tweaks
    [hierophone.kicad_pcb, hierophone.kicad_sch, power.kicad_sch]
2025-07-30 Make sure to specify the lm386n-4
    [hierophone.kicad_sch]
2025-07-30 Redesign panel and PCB to have heat vents for power amp
    [hierophone.kicad_pcb, panel-holes.dxf]
2025-08-01 Regenerating gerbers
    [hierophone-B_Cu.gbl, hierophone-B_Mask.gbs, hierophone-B_Silkscreen.gbo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]

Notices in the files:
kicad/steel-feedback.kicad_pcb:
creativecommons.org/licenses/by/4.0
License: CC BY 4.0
